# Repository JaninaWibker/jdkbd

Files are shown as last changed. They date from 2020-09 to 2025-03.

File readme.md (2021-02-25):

Jade keyboard (based on crkbd)

The Jade keyboard is a split 40% ortholinear mechanical keyboard (*that's a lot of words*) which
(optionally) has a thinkpad trackpoint attachment on the right half.

> **WARNING**: THIS IS STILL IN DEVELOPMENT AND MIGHT BE COMPLETELY UNUSABLE

keyboard layout

The red key represents the trackpoint [keyboard-layout-editor](http://www.keyboard-layout-editor.com/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,%3B&@_y:-0.75&x:2%3B&=X&_x:1%3B&=V&=B&_x:2.5%3B&=N&=M&_x:1%3B&=.%3B&@_y:-0.75%3B&=&=Z&_x:10.5%3B&=-&=%3B&@_y:-0.25&x:2.75%3B&=&_x:7%3B&=%3B&@_y:-0.75%3B&=&_x:0.25%3B&=&_x:10%3B&=&=%3B&@_r:15&rx:7.25&ry:3.5&y:0.25&x:-2%3B&=%3B&@_y:-0.5&x:-3%3B&=%3B&@_ry:3.75&y:1&x:-2%3B&=%3B&@_r:-15&ry:3.5&y:0.25&x:1%3B&=%3B&@_y:-0.5&x:2%3B&=%3B&@_ry:3.75&y:1&x:1%3B&=)

<p align="center">
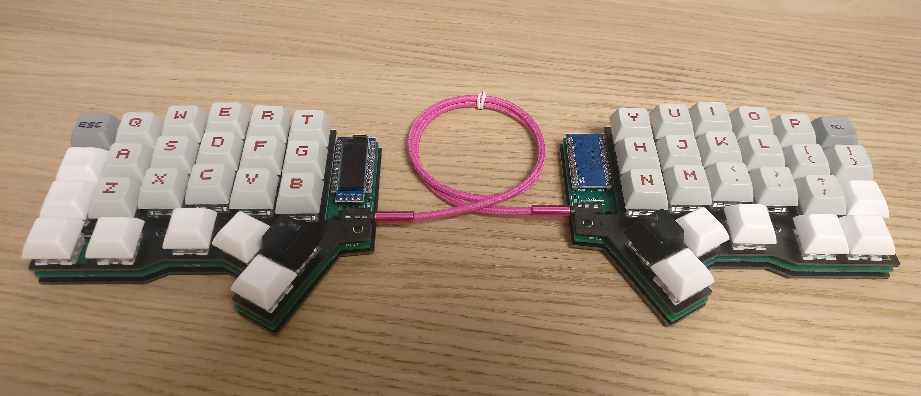
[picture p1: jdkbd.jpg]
jdkbd without trackpoint
  
  <span>jdkbd without trackpoint</span>
</p>

The whole project is based on the [corne keyboard](https://github.com/foostan/crkbd) by foostan but
has undergone many modifications. Still, a lot of work has been saved duo to the work done
by foostan.

The main differences between the corne and the jade are that:
- corne has 4 less keys (44 vs 48; jade has a bottom row and thumb cluster while the corne only has
  a thumb cluster)
- corne is (depending on the model) reversible; the jade uses kailh hot-swap sockets which are also
  supported by the corne-cherry version (which is also not reversible)
- corne has more case options available, the jade currently only has "pcb case"

## Getting the keyboard

The current method to getting a jade keyboard is letting it be manufactured by jlcpcb, pcbway or a
different pcb manufacturer. There are no kits available.

> Almost all pcb manufacturers have a minimum order quantity of 5pc; getting 5 times the pieces you
> need might still be cheaper than some other keyboard kits and you can possibly resell them.

The keyboard comes in 3 different parts: the pcb, the bottom plate and the top plate.

## Building and needed components

You mainly need kailh hot-swap sockets, screws, LEDs and ProMicro's

The full list can be found [here](/components.md) along with some cost estimates.

Build instructions can be found [here](/build-instructions.md).

## Modifying the keyboard

The keyboard was designed in [KiCad](https://https://kicad-pcb.org/) and uses some of
[foostan's footprints / symbols](https://github.com/foostan/kbd) for custom keyboards, as well as a few
standard KiCad libraries (power & led).

These should be directly available when cloning the repo **with submodules**. This can be done by
using

```sh
git clone --recursive [url]
```

when cloning the repo initially or later on using

```sh
git submodule update --init --recursive
```

A few beginner mistakes I made / faced are:
- not working with eeschema and jumping straight into pcbnew (the pcb designer)
- not caring about aligning things to the grid (KiCad really likes it's grid)

Make sure that the paths for the additional symbols and footprints are configured correctly. It should
look something like this:

footprints: 

| nickname | library path |
| --- | --- |
| kbd | `${KIPRJMOD}/kbd/kicad-footprints/kbd.pretty` |
| logo | `${KIPRJMOD}/../logo-footprints` |

symbols:

| nickname | library path |
| --- | --- |
| kbd | `${KIPRJMOD}/kbd/kicad-symbols/kbd.lib` |
| power | `${KIPRJMOD}/libraries/kicad-symbols/power.lib` |
| LED | `${KIPRJMOD}/libraries/kicad-symbols/LED.lib` |

When using KiCad 5.1.6 the pick and place file (also called .pos file) might be incorrect. Using
later versions will probably fix this as well as prior versions as this is a bug that was introduced
while fixing another bug.

Incase you are using KiCad 5.1.6 the error is easy to correct: the x-coordinate in the (csv) file is
simply flipped. Just flip it back and you are fine.

If you are using JLCPCB for manufacturing you can use their preview while ordering to check that everything
is alright. 

> Modifying the PCB can require also modifying the bottom- and top-plate.

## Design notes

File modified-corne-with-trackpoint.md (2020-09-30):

# Modified Corne with Trackpoint

| Name | Amount | Notes | Link | Price |
| --- | --- | --- | --- | --- |
| PCB | 2 | PCBs differ | TBD | ~30€/5pc |
| Top plate | 2 | plates probably differ | TBD | ~10€/5pc |
| Bottom plate | 2 | plates probably differ | TBD | ~10€/5pc |
| ProMicro protective plate | 2 | the acrylic shield on top of the pro micro - teal (1 needed with trackpoint thingy) | [keyhive](https://keyhive.xyz/shop/corne-helidox-oled-acrylic-covers) | \$2/pc - \$2 |
| ProMicro | 2 | | [ebay](https://www.ebay.de/itm/Arduino-Pro-Micro-5V-16MHz-Leonardo-ATMega32U4-32k-EntwicklungsBoard-microUSB/172093871231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) | 7€/pc - 14€ |
| Kailh hot swap PCB socket | 46 | | [kbdfans](https://kbdfans.com/products/mechanical-keyboard-switches-kailh-pcb-socket) | $0.1/pc - \$4.6 |
| Switches | 46 | maybe different switches for different keys | TBD | TBD |
| Keycaps | 46 | all 1u | TBD | TBD |
| LEDs | 58 | 46 mounted upwards, 12 mounted downwards (quantity of 50 on keyhive) [led pinout](https://ae01.alicdn.com/kf/HTB1WQS4KpXXXXa5XFXXq6xXFXXX5/201454003/HTB1WQS4KpXXXXa5XFXXq6xXFXXX5.jpg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) from [here](https://www.aliexpress.com/item/32623583544.html) | [keyhive](https://keyhive.xyz/shop/cornehelidox-rgb-leds) | \$8/50pc - \$8 |
| TRRS jack | 2 | | [aliexpress](https://www.aliexpress.com/item/33029465106.html) | \$0.80/10pc - \$0.80 |
| diode | 46 | may already own these if not SMD | [keyhive](https://keyhive.xyz/shop/diodes) | \$3/60pc - \$3 |
| OLED module | 1 | only need one because of trackpoint thingy | [keyhive](https://keyhive.xyz/shop/corne-helidox-oleds) | \$9/pc - \$9 |
| 4-pin headers | 2 | probably own those already | none | — |
| 4-pin sockets | 2 | probably own those already | none | — |
| rubber cushions | 8 | ? | TBD | TBD |
| Spacer M2 8mm | 4 | check out build logs and that one reddit post about these things | [ebay](https://www.ebay.de/itm/25-100pcs-Black-Plastic-Nylon-M2-M3-M4-Hex-Column-Standoff-Spacer-Phillips-Screw/303307496332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) | ~3€/25pc - ~3€ |
| Spacer M2 6.5mm | 10 | ? | TBD | TBD |
| Screw M2 4mm | 28 | ? | TBD | TBD |
| rubber feet | a few  | | | |
| TRS / TRRS cable | 1 | keyhive - white | [keyhive](https://keyhive.xyz/shop/trrs-cable) | $3/pc |
| | | | | |
| MicroUSB cable | 1 | | none | — |
| Trackpoint module | 1 | gotta extract it from an actual keyboard | [aliexpress](https://www.aliexpress.com/item/32839727211.html) | \$11 |
| | | | | |
| | | | | |

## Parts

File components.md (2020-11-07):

# Components

> **warning**: some things might still be missing

| name | amount | notes | price | link |
| --- | --- | ----- | --- | --- |
| PCB | 2 | jlcpcb allows min. order quantity of 5pc | ~10€/pc | - |
| Bottom plate | 2 | jlcpcb allows min. order quantity of 5pc | ~4€/pc  | - |
| Top plate | 2 | jlcpcb allows min. order quantity of 5pc | ~4€/pc  | - |
| ProMicro | 2 | - | 7€/pc | [ebay](https://www.ebay.de/itm/Pro-Micro-kompatibel-ATmega32U4-5V-Micro-USB-Board-Arduino-16MHz-Leonardo/253565177853) |
| ProMicro protective plate | 2 | one is used to lock trackpoint in place; needs additional holes | 2€/pc | [keyhive](https://keyhive.xyz/shop/corne-helidox-oled-acrylic-covers) |
| Kailh hot swap sockets | 48 | - | \$0.10/pc | [kbdfans](https://kbdfans.com/products/mechanical-keyboard-switches-kailh-pcb-socket) | |
| LEDs | 48 | SK6812 3535; will most likely destroy a few; better to buy a bit more | \$10/100pc | [aliexpress](https://www.aliexpress.com/item/32623583544.html) |
| Switches | 48 | choose yourself | - | - |
| Keycaps | 48 (1u) | choose yourself | - | - |
| TRRS jack | 2 | - | \$0.80/10pc | [aliexpress](https://www.aliexpress.com/item/33029465106.html) |
| OLED module | 1 | need 2 when not using trackpoint	 | 9€/pc | [keyhive](https://keyhive.xyz/shop/corne-helidox-oleds) |
| 4-pin headers | a few | needed when not soldering promicro directly to pcb | - | - |
| 4-pin sockets | a few | needed when not soldering promicro directly to pcb | - | - |
| M2 Spacers (8mm) | a few | ideally 6.8mm, 8 works too | \$2/50pc | [aliexpress](https://www.aliexpress.com/item/4000258424928.html) |
| M2 Washers (M2x5x1mm) | a few | - | \$1/100pc | [aliexpress](https://www.aliexpress.com/item/33021883302.html) |
| M2 Screws | a few | kit includes lot's of diff. screws | \$3.20/250pc | [aliexpress](https://www.aliexpress.com/item/10000188653527.html) |
| rubber feet | 8 or more | | \$1/50pc | [aliexpress](https://www.aliexpress.com/item/4000266239818.html) |
| TRS/TRRS cable | 1 | many diff. options available | 3€/pc | [keyhive](https://keyhive.xyz/shop/trrs-cable) |
| MicroUSB cable | 1 | - | - | - |
| Trackpoint module | 1 | this needs to be extracted from an actual keyboard | \$11/pc | [aliexpress](https://www.aliexpress.com/item/32839727211.html) |

> having 60/40 solder is apparently also a good idea; [aliexpress](https://www.aliexpress.com/item/4001261573295.html)

> [this guide](https://www.reddit.com/r/crkbd/comments/esv3i8/guide_corne_diy_kit/) for the corne is pretty much fully applicable to the jade as well

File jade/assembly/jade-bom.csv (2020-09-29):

Comment | Designator | Footprint | LCSC
D | D1,D2,D3,D4,D5,D6,D7,D8,D9,D10,D11,D12,D13,D14,D15,D16,D17,D18,D19,D20,D21,D22,D23,D24,D25,D26,D27,D28,D29,D30,D31,D32,D33,D34,D35,D36,D37,D38,D39,D40,D41,D42,D43,D44,D45,D46,D47,D48 | kbd:D3_SMD_v2 | C81598
MJ-4PP-9 | J1,J3 | kbd:MJ-4PP-9_1side
OLED | J2,J4 | kbd:OLED_1side
WS2812B | LED1,LED2,LED3,LED4,LED5,LED6,LED28,LED29,LED30,LED31,LED32,LED33 | LED_SMD:LED_WS2812B_PLCC4_5.0x5.0mm_P3.2mm | C114586
YS-SK6812MINI-E | LED7,LED8,LED9,LED10,LED11,LED12,LED13,LED14,LED15,LED16,LED17,LED18,LED19,LED20,LED21,LED22,LED23,LED24,LED25,LED26,LED27,LED34,LED35,LED36,LED37,LED38,LED39,LED40,LED41,LED42,LED43,LED44,LED45,LED46,LED47,LED48,LED49,LED50,LED51,LED52,LED53,LED54,LED55,LED56,LED57,LED58,LED59,LED60 | kbd:YS-SK6812MINI-E | SW_PUSH" | RSW1,RSW2 | kbd:ResetSW_1side
SW_PUSH | SW1,SW2,SW3,SW4,SW5,SW6,SW7,SW8,SW9,SW10,SW11,SW12,SW13,SW14,SW15,SW16,SW17,SW18,SW19,SW20,SW22,SW23,SW24,SW25,SW26,SW27,SW28,SW29,SW30,SW31,SW32,SW33,SW34,SW35,SW36,SW37,SW38,SW39,SW40,SW41,SW43,SW44,SW45,SW46,SW47,SW48 | kbd:CherryMX_Hotswap
SW_PUSH | SW21,SW42 | kbd:CherryMX_Hotswap_1.5u
ProMicro | U1,U2 | kbd:ProMicro_v2_1side

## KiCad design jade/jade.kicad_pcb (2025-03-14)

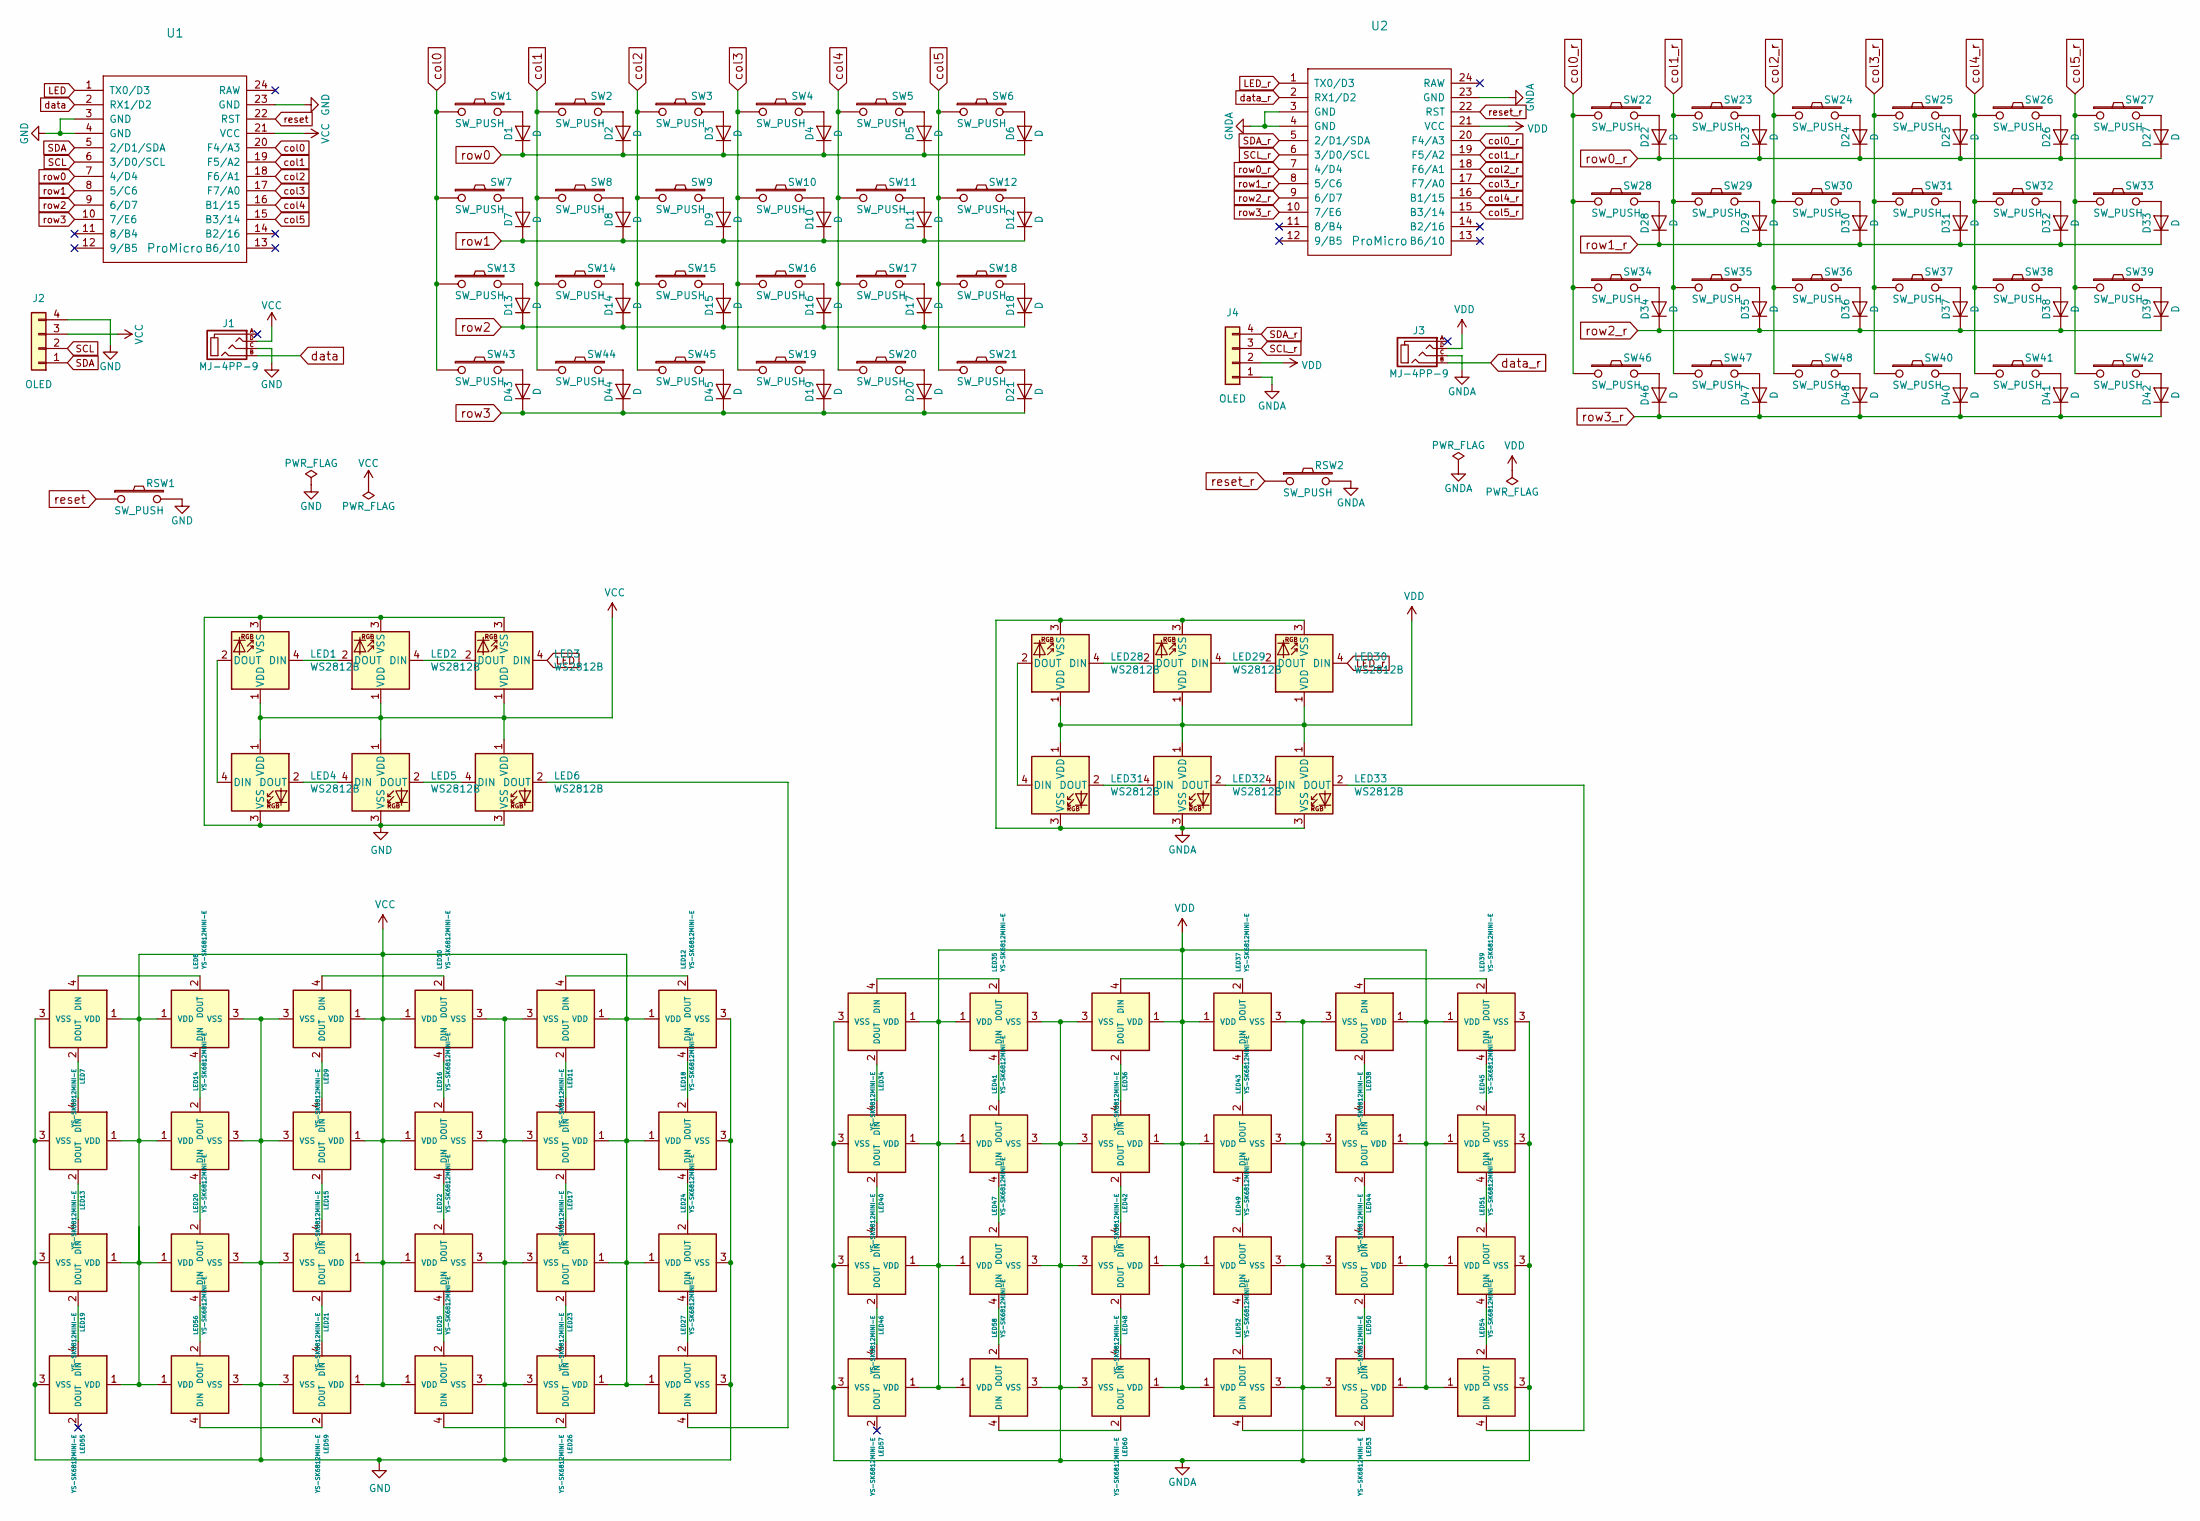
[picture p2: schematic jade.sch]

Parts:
D1, D2, D3, D4, D5, D6, D7, D8, D9, D10, D11, D12, D13, D14, D15, D16, D17, D18, D19, D20, D21, D22, D23, D24, D25, D26, D27, D28, D29, D30, D31, D32, D33, D34, D35, D36, D37, D38, D39, D40, D41, D42, D43, D44, D45, D46, D47, D48: D; D3_SMD_v2; LCSC Part # C81598
J1, J3: MJ-4PP-9; MJ-4PP-9_1side
J2, J4: OLED; OLED_1side
LED1, LED2, LED3, LED4, LED5, LED6, LED28, LED29, LED30, LED31, LED32, LED33: WS2812B; LED_WS2812B_PLCC4_5.0x5.0mm_P3.2mm; LCSC Part # C114586
LED7, LED8, LED9, LED10, LED11, LED12, LED13, LED14, LED15, LED16, LED17, LED18, LED19, LED20, LED21, LED22, LED23, LED24, LED25, LED26, LED27, LED34, LED35, LED36, LED37, LED38, LED39, LED40, LED41, LED42, LED43, LED44, LED45, LED46, LED47, LED48, LED49, LED50, LED51, LED52, LED53, LED54, LED55, LED56, LED57, LED58, LED59, LED60: YS-SK6812MINI-E
RSW1, RSW2: SW_PUSH; ResetSW_1side
SW1, SW2, SW3, SW4, SW5, SW6, SW7, SW8, SW9, SW10, SW11, SW12, SW13, SW14, SW15, SW16, SW17, SW18, SW19, SW20, SW22, SW23, SW24, SW25, SW26, SW27, SW28, SW29, SW30, SW31, SW32, SW33, SW34, SW35, SW36, SW37, SW38, SW39, SW40, SW41, SW43, SW44, SW45, SW46, SW47, SW48: SW_PUSH; CherryMX_Hotswap
SW21, SW42: SW_PUSH; CherryMX_Hotswap_1.5u
U1, U2: ProMicro; ProMicro_v2_1side

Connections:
GND: J1.C, J2.4, LED1.3 (VSS), LED2.3 (VSS), LED3.3 (VSS), LED4.3 (VSS), LED5.3 (VSS), LED6.3 (VSS), LED7.3 (VSS), LED8.3 (VSS), LED9.3 (VSS), LED10.3 (VSS), LED11.3 (VSS), LED12.3 (VSS), LED13.3 (VSS), LED14.3 (VSS), LED15.3 (VSS), LED16.3 (VSS), LED17.3 (VSS), LED18.3 (VSS), LED19.3 (VSS), LED20.3 (VSS), LED21.3 (VSS), LED22.3 (VSS), LED23.3 (VSS), LED24.3 (VSS), LED25.3 (VSS), LED26.3 (VSS), LED27.3 (VSS), LED55.3 (VSS), LED56.3 (VSS), LED59.3 (VSS), RSW1.2, U1.3 (GND), U1.4 (GND), U1.23 (GND)
GNDA: J3.C, J4.1, LED28.3 (VSS), LED29.3 (VSS), LED30.3 (VSS), LED31.3 (VSS), LED32.3 (VSS), LED33.3 (VSS), LED34.3 (VSS), LED35.3 (VSS), LED36.3 (VSS), LED37.3 (VSS), LED38.3 (VSS), LED39.3 (VSS), LED40.3 (VSS), LED41.3 (VSS), LED42.3 (VSS), LED43.3 (VSS), LED44.3 (VSS), LED45.3 (VSS), LED46.3 (VSS), LED47.3 (VSS), LED48.3 (VSS), LED49.3 (VSS), LED50.3 (VSS), LED51.3 (VSS), LED52.3 (VSS), LED53.3 (VSS), LED54.3 (VSS), LED57.3 (VSS), LED58.3 (VSS), LED60.3 (VSS), RSW2.2, U2.3 (GND), U2.4 (GND), U2.23 (GND)
LED: LED3.4 (DIN), U1.1 (TX0/D3)
LED_r: LED30.4 (DIN), U2.1 (TX0/D3)
unnamed: D1.2 (A), SW1.2
unnamed: D2.2 (A), SW2.2
unnamed: D3.2 (A), SW3.2
unnamed: D4.2 (A), SW4.2
unnamed: D5.2 (A), SW5.2
unnamed: D6.2 (A), SW6.2
unnamed: D7.2 (A), SW7.2
unnamed: D8.2 (A), SW8.2
unnamed: D9.2 (A), SW9.2
unnamed: D10.2 (A), SW10.2
unnamed: D11.2 (A), SW11.2
unnamed: D12.2 (A), SW12.2
unnamed: D13.2 (A), SW13.2
unnamed: D14.2 (A), SW14.2
unnamed: D15.2 (A), SW15.2
unnamed: D16.2 (A), SW16.2
unnamed: D17.2 (A), SW17.2
unnamed: D18.2 (A), SW18.2
unnamed: D19.2 (A), SW19.2
unnamed: D20.2 (A), SW20.2
unnamed: D21.2 (A), SW21.2
unnamed: D22.2 (A), SW22.2
unnamed: D23.2 (A), SW23.2
unnamed: D24.2 (A), SW24.2
unnamed: D25.2 (A), SW25.2
unnamed: D26.2 (A), SW26.2
unnamed: D27.2 (A), SW27.2
unnamed: D28.2 (A), SW28.2
unnamed: D29.2 (A), SW29.2
unnamed: D30.2 (A), SW30.2
unnamed: D31.2 (A), SW31.2
unnamed: D32.2 (A), SW32.2
unnamed: D33.2 (A), SW33.2
unnamed: D34.2 (A), SW34.2
unnamed: D35.2 (A), SW35.2
unnamed: D36.2 (A), SW36.2
unnamed: D37.2 (A), SW37.2
unnamed: D38.2 (A), SW38.2
unnamed: D39.2 (A), SW39.2
unnamed: D40.2 (A), SW40.2
unnamed: D41.2 (A), SW41.2
unnamed: D42.2 (A), SW42.2
unnamed: D43.2 (A), SW43.2
unnamed: D44.2 (A), SW44.2
unnamed: D45.2 (A), SW45.2
unnamed: D46.2 (A), SW46.2
unnamed: D47.2 (A), SW47.2
unnamed: D48.2 (A), SW48.2
unnamed: LED1.2 (DOUT), LED4.4 (DIN)
unnamed: LED1.4 (DIN), LED2.2 (DOUT)
unnamed: LED2.4 (DIN), LED3.2 (DOUT)
unnamed: LED4.2 (DOUT), LED5.4 (DIN)
unnamed: LED5.2 (DOUT), LED6.4 (DIN)
unnamed: LED7.4 (DIN), LED8.2 (DOUT)
unnamed: LED9.4 (DIN), LED10.2 (DOUT)
unnamed: LED10.4 (DIN), LED16.2 (DOUT)
unnamed: LED11.2 (DOUT), LED17.4 (DIN)
unnamed: LED11.4 (DIN), LED12.2 (DOUT)
unnamed: LED12.4 (DIN), LED18.2 (DOUT)
unnamed: LED13.2 (DOUT), LED19.4 (DIN)
unnamed: LED7.2 (DOUT), LED13.4 (DIN)
unnamed: LED8.4 (DIN), LED14.2 (DOUT)
unnamed: LED14.4 (DIN), LED20.2 (DOUT)
unnamed: LED15.2 (DOUT), LED21.4 (DIN)
unnamed: LED9.2 (DOUT), LED15.4 (DIN)
unnamed: LED16.4 (DIN), LED22.2 (DOUT)
unnamed: LED17.2 (DOUT), LED23.4 (DIN)
unnamed: LED18.4 (DIN), LED24.2 (DOUT)
unnamed: LED19.2 (DOUT), LED55.4 (DIN)
unnamed: LED20.4 (DIN), LED56.2 (DOUT)
unnamed: LED21.2 (DOUT), LED59.4 (DIN)
unnamed: LED22.4 (DIN), LED25.2 (DOUT)
unnamed: LED23.2 (DOUT), LED26.4 (DIN)
unnamed: LED24.4 (DIN), LED27.2 (DOUT)
unnamed: LED25.4 (DIN), LED26.2 (DOUT)
unnamed: LED6.2 (DOUT), LED27.4 (DIN)
unnamed: LED28.2 (DOUT), LED31.4 (DIN)
unnamed: LED28.4 (DIN), LED29.2 (DOUT)
unnamed: LED29.4 (DIN), LED30.2 (DOUT)
unnamed: LED31.2 (DOUT), LED32.4 (DIN)
unnamed: LED32.2 (DOUT), LED33.4 (DIN)
unnamed: LED33.2 (DOUT), LED54.4 (DIN)
unnamed: LED34.2 (DOUT), LED40.4 (DIN)
unnamed: LED34.4 (DIN), LED35.2 (DOUT)
unnamed: LED35.4 (DIN), LED41.2 (DOUT)
unnamed: LED36.2 (DOUT), LED42.4 (DIN)
unnamed: LED36.4 (DIN), LED37.2 (DOUT)
unnamed: LED37.4 (DIN), LED43.2 (DOUT)
unnamed: LED38.2 (DOUT), LED44.4 (DIN)
unnamed: LED38.4 (DIN), LED39.2 (DOUT)
unnamed: LED39.4 (DIN), LED45.2 (DOUT)
unnamed: LED40.2 (DOUT), LED46.4 (DIN)
unnamed: LED41.4 (DIN), LED47.2 (DOUT)
unnamed: LED42.2 (DOUT), LED48.4 (DIN)
unnamed: LED43.4 (DIN), LED49.2 (DOUT)
unnamed: LED44.2 (DOUT), LED50.4 (DIN)
unnamed: LED45.4 (DIN), LED51.2 (DOUT)
unnamed: LED46.2 (DOUT), LED57.4 (DIN)
unnamed: LED47.4 (DIN), LED58.2 (DOUT)
unnamed: LED48.2 (DOUT), LED60.4 (DIN)
unnamed: LED49.4 (DIN), LED52.2 (DOUT)
unnamed: LED50.2 (DOUT), LED53.4 (DIN)
unnamed: LED51.4 (DIN), LED54.2 (DOUT)
unnamed: LED52.4 (DIN), LED53.2 (DOUT)
unnamed: LED56.4 (DIN), LED59.2 (DOUT)
unnamed: LED58.4 (DIN), LED60.2 (DOUT)
SCL: J2.2, U1.6 (3/D0/SCL)
SCL_r: J4.3, U2.6 (3/D0/SCL)
SDA: J2.1, U1.5 (2/D1/SDA)
SDA_r: J4.4, U2.5 (2/D1/SDA)
VCC: J1.D, J2.3, LED1.1 (VDD), LED2.1 (VDD), LED3.1 (VDD), LED4.1 (VDD), LED5.1 (VDD), LED6.1 (VDD), LED7.1 (VDD), LED8.1 (VDD), LED9.1 (VDD), LED10.1 (VDD), LED11.1 (VDD), LED12.1 (VDD), LED13.1 (VDD), LED14.1 (VDD), LED15.1 (VDD), LED16.1 (VDD), LED17.1 (VDD), LED18.1 (VDD), LED19.1 (VDD), LED20.1 (VDD), LED21.1 (VDD), LED22.1 (VDD), LED23.1 (VDD), LED24.1 (VDD), LED25.1 (VDD), LED26.1 (VDD), LED27.1 (VDD), LED55.1 (VDD), LED56.1 (VDD), LED59.1 (VDD), U1.21 (VCC)
VDD: J3.D, J4.2, LED28.1 (VDD), LED29.1 (VDD), LED30.1 (VDD), LED31.1 (VDD), LED32.1 (VDD), LED33.1 (VDD), LED34.1 (VDD), LED35.1 (VDD), LED36.1 (VDD), LED37.1 (VDD), LED38.1 (VDD), LED39.1 (VDD), LED40.1 (VDD), LED41.1 (VDD), LED42.1 (VDD), LED43.1 (VDD), LED44.1 (VDD), LED45.1 (VDD), LED46.1 (VDD), LED47.1 (VDD), LED48.1 (VDD), LED49.1 (VDD), LED50.1 (VDD), LED51.1 (VDD), LED52.1 (VDD), LED53.1 (VDD), LED54.1 (VDD), LED57.1 (VDD), LED58.1 (VDD), LED60.1 (VDD), U2.21 (VCC)
col0: SW1.1, SW7.1, SW13.1, SW43.1, U1.20 (F4/A3)
col0_r: SW22.1, SW28.1, SW34.1, SW46.1, U2.20 (F4/A3)
col1: SW2.1, SW8.1, SW14.1, SW44.1, U1.19 (F5/A2)
col1_r: SW23.1, SW29.1, SW35.1, SW47.1, U2.19 (F5/A2)
col2: SW3.1, SW9.1, SW15.1, SW45.1, U1.18 (F6/A1)
col2_r: SW24.1, SW30.1, SW36.1, SW48.1, U2.18 (F6/A1)
col3: SW4.1, SW10.1, SW16.1, SW19.1, U1.17 (F7/A0)
col3_r: SW25.1, SW31.1, SW37.1, SW40.1, U2.17 (F7/A0)
col4: SW5.1, SW11.1, SW17.1, SW20.1, U1.16 (B1/15)
col4_r: SW26.1, SW32.1, SW38.1, SW41.1, U2.16 (B1/15)
col5: SW6.1, SW12.1, SW18.1, SW21.1, U1.15 (B3/14)
col5_r: SW27.1, SW33.1, SW39.1, SW42.1, U2.15 (B3/14)
data: J1.B, U1.2 (RX1/D2)
data_r: J3.B, U2.2 (RX1/D2)
reset: RSW1.1, U1.22 (RST)
reset_r: RSW2.1, U2.22 (RST)
row0: D1.1 (K), D2.1 (K), D3.1 (K), D4.1 (K), D5.1 (K), D6.1 (K), U1.7 (4/D4)
row0_r: D22.1 (K), D23.1 (K), D24.1 (K), D25.1 (K), D26.1 (K), D27.1 (K), U2.7 (4/D4)
row1: D7.1 (K), D8.1 (K), D9.1 (K), D10.1 (K), D11.1 (K), D12.1 (K), U1.8 (5/C6)
row1_r: D28.1 (K), D29.1 (K), D30.1 (K), D31.1 (K), D32.1 (K), D33.1 (K), U2.8 (5/C6)
row2: D13.1 (K), D14.1 (K), D15.1 (K), D16.1 (K), D17.1 (K), D18.1 (K), U1.9 (6/D7)
row2_r: D34.1 (K), D35.1 (K), D36.1 (K), D37.1 (K), D38.1 (K), D39.1 (K), U2.9 (6/D7)
row3: D19.1 (K), D20.1 (K), D21.1 (K), D43.1 (K), D44.1 (K), D45.1 (K), U1.10 (7/E6)
row3_r: D40.1 (K), D41.1 (K), D42.1 (K), D46.1 (K), D47.1 (K), D48.1 (K), U2.10 (7/E6)

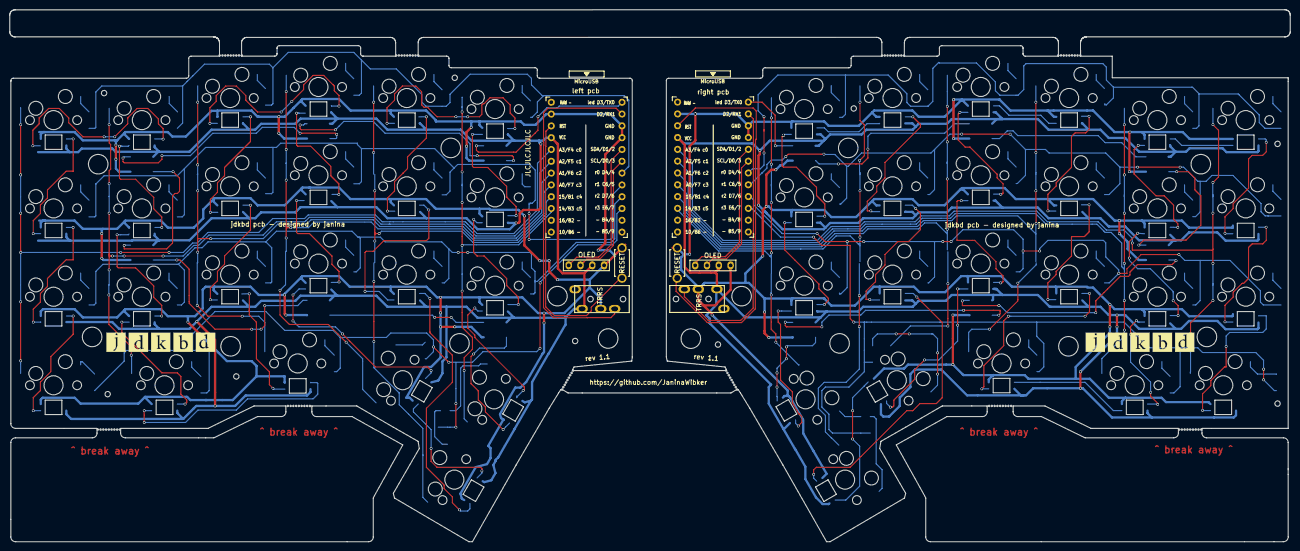
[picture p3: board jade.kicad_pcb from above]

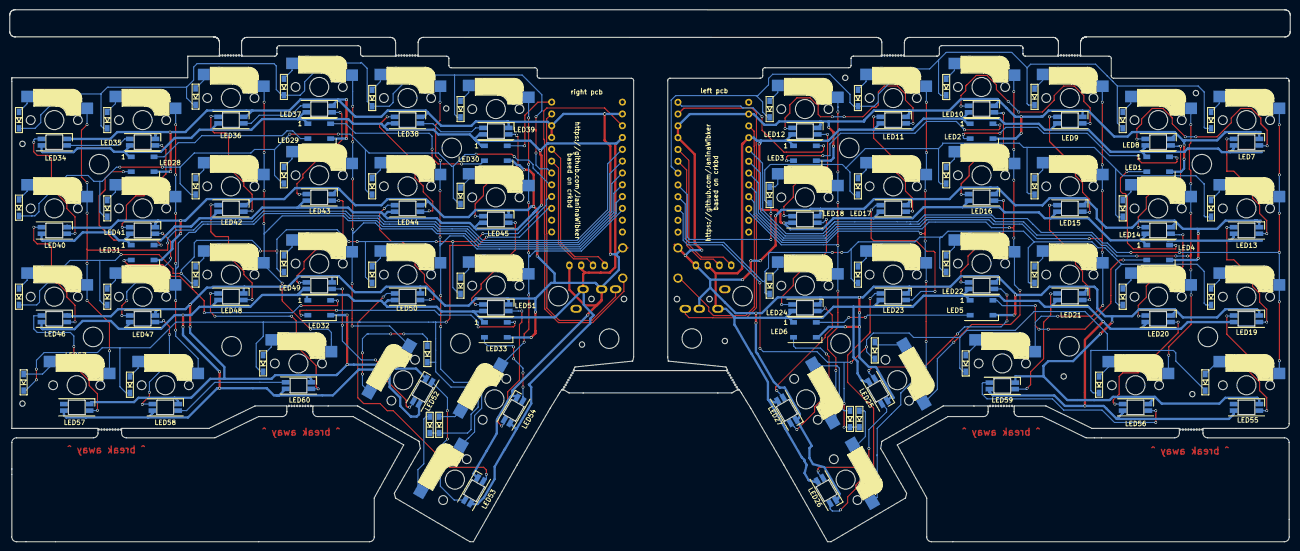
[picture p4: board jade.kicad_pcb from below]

Board: 2 copper layers, 275.5 x 114.5 mm, 178 parts (115 on the bottom side), 140 nets.

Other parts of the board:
Ref**: Val**; M2_HOLE_v2
Ref**#2, Ref**#3, Ref**#4, Ref**#5, Ref**#6, Ref**#7, Ref**#8, Ref**#9, Ref**#10, Ref**#11, Ref**#12, Ref**#13, Ref**#14: Val**; M2_HOLE_v2

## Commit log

2020-09-27 finished pcb design; minor improvements are still to be expected
    [corne-cherry.kicad_pcb]
2020-09-28 updated schematic and pcb
    schematic: fixed unconnected pins and aligned some components to the grid
    pcb: updated wires according to new schematic, created outline (edge
    cuts layer), added a few more labels, fixed a few smaller mistakes
    [corne-cherry.kicad_pcb, corne-cherry.sch]
2020-09-28 added gerber files and added even more lables to the pcb
    [corne-cherry-B_Cu.gbr, corne-cherry-B_Mask.gbr, corne-cherry-B_SilkS.gbr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]
2020-09-28 added zip of gerber files and assembly related files
    [corne-cherry.kicad_pcb, corne-cherry.sch, cornetrack-footprint-positions.csv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]
2020-09-29 renamed project, diode rotation, assembly - renamed project from corne-cherry to cornetrack - tried to have all diodes rotated the same way - did numerous assembly related shenanigans; this is all in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
    [corne-cherry-B_Cu.gbr, corne-cherry-B_Mask.gbr, corne-cherry-B_SilkS.gbr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]
2020-09-29 added bottom-plate as subproject (has no real schematic; only pcb)
    [bottom-plate-B_Cu.gbr, bottom-plate-B_Mask.gbr, bottom-plate-B_Paste.gbr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]
2020-09-30 regenerated gerber files
    [corne-cherry-NPTH.drl, corne-cherry-PTH.drl, cornetrack-B_Cu.gbr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]
2020-09-30 made all holes and almost all diodes on both pcbs symmetric to each other (meaning that accidentally having all coordinates in the .pos file inverted would not cause a big problem for almost all of t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
    [cornetrack.kicad_pcb]
2020-09-30 added top-plate (works for both sides / pcbs)
    [cornetrack-top-plate.kicad_pcb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]
2020-09-30 moved almost everything into the new jade directory
    [cornetrack-B_Cu.gbr, cornetrack-B_Mask.gbr, cornetrack-B_SilkS.gbr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]
2020-10-01 added logos on silkscreen and plotted all gerber files again
    [bottom-plate-B_Cu.gbr, bottom-plate-B_Mask.gbr, bottom-plate-B_Paste.gbr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]
2020-10-01 moved tracks further away from edges
    [cornetrack-B_Cu.gbr, cornetrack-B_Mask.gbr, cornetrack-B_SilkS.gbr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]
2020-10-05 made top and bottom plate a tiny bit larger in order to increase distance between edge cuts to >2mm
    [bottom-plate-B_Cu.gbr, bottom-plate-B_Mask.gbr, bottom-plate-B_Paste.gbr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]
2020-10-05 changed name again (cornetrack -> jade)
    [cornetrack-all-pos-2.csv, cornetrack-all-pos.csv, jade-B_Cu.gbr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]
2020-10-29 added breakout tabs and made pcb mostly rectangular
    [jade.kicad_pcb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]
2020-10-30 added "break away" text to break away thingies
    [jade.kicad_pcb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]
2020-10-31 added missing drill files :/
    [bottom-plate.drl, jade-top-plate-B_Cu.gbr, jade-top-plate-B_Mask.gbr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]
2025-03-14 update things
    [jade.kicad_pcb, jade.sch]
